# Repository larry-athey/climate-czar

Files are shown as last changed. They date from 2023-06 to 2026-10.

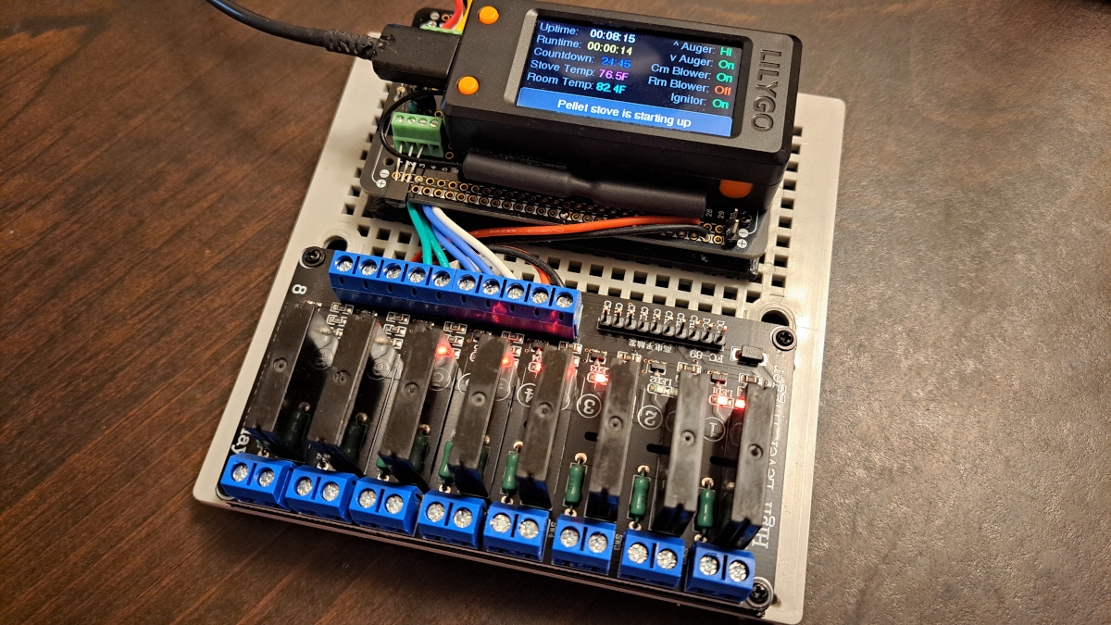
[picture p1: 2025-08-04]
Diagrams/Pellet-Stove-Controller-Assembly.jpg

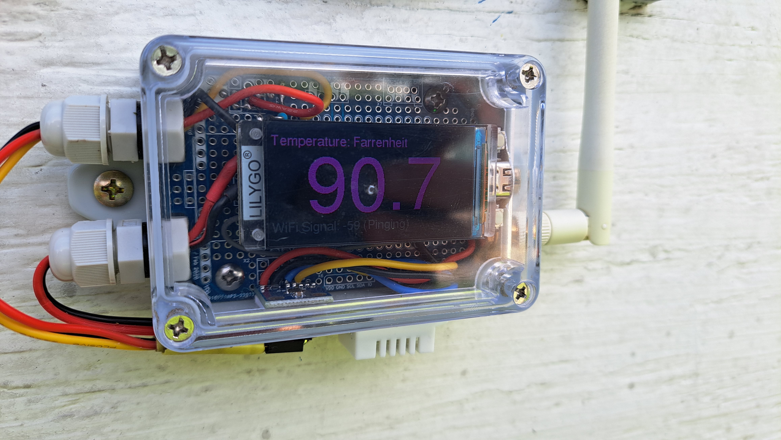
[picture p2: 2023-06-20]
CZ_Outdoor_Monitor/Outdoor-Monitor.jpg

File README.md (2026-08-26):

# Climate Czar
Universal remote climate monitoring and management system for greenhouses and indoor grow operations. No hardware brand dependencies, if you can read or control a sensor or smart switch from the command line, then it's compatible with Climate Czar.

Live demo at https://greenhouse.panhandleponics.com/cz/?CZ_THEME=1<br>
Buy a pre-built Climate Czar server at https://3dgtower.com

You may also contact me directly at https://panhandleponics.com<br>
Subscribe to the official YouTube channel at https://www.youtube.com/@PanhandlePonics

_...No, I don't use AI to design and build my projects, I actually still know how to use my brain..._

---
<br>
---

Climate Czar is a Linux based system that gathers readings from any type of sensor or switch that can be read from the command line, whether it is a local device connected to a GPIO bus or a network device. By the same token, the system will control output switches that can also be toggled from the command line. There are no brand/model hardware dependencies, you can even use it with your own custom IoT devices.

Most smart home devices are controllable from the command line of your computer over your network. For example, you can download a utility for TP-Link/Kasa devices from https://github.com/python-kasa/python-kasa for this or you can write scripts for this that use standard command line tools in Linux and MacOS. There are many other brands with this capability as well.

Virtual input sensors/switches can be created that return the average of multiple variable value sensors _(temperature, humidity, etc)_ as well as AND/OR/NOT logic gates based on multiple binary switch type input sensors.

Enabling of output switches may be over-ridden by the status of another output switch. For example, an output switch that controls exhaust fans can be disabled if another switch running a heater is turned on. However, you can manually over-ride this if need be.

Output switches really don't even have to physically exist. Since their operation is controlled with on/off bash scripts, these scripts can also be used to send email/SMS notifications or even make a curl URL call. Input sensors/switches can be assigned to multiple output switches, so you can easily receive a notification at the same time that a physical output switch is toggled on or off.

All connected devices can be assigned to separate groups which allows you to have separate dashboards for multiple greenhouses or grow operations. There's no limit to the number of attached devices and groups. This system running on an Orange Pi 3B with 8GB of RAM was tested with 500 virtual devices and still completed all read and write operations within the every-15-seconds processing loop.

This system will run effectively on a Raspberry PI or clone, or any Linux powered web server that supports PHP and MySQL. The Climate Czar server itself could actually monitor and control multiple greenhouses and grow operations in different locations if network enabled sensors and switches are utilized throughout with an on-site Raspberry Pi running an Nginx reverse proxy.

### Input Device Types
1.	Variable Value Sensor (Temperature, Humidity, pH, EC, AD Convertor, etc)
2.	Average From a Group of Variable Value Sensors
3.	Remote Switch (Float Switch, Door/Window Switch, Photocell Switch, etc)
4.	AND Gate of a Group of Remote Switches
5.	OR Gate of a Group of Remote Switches
6.	NOT Gate of a Group of Remote Switches
7.	Scheduler (unlimited on/off schedules per day)
8.	Web Console Switch (Only controllable via web UI)
9.	Raw Text Output Device (only for displaying text, cannot be used as a controller)

The virtual input devices are where the Climate Czar really shines because they allow you to consider multiple sample points before taking action. For example, having temperature sensors on the east and west ends of a greenhouse. Each one of those could be reporting significantly different temperatures at the same time. It makes more sense to turn on heating or cooling based on the average temperature.

Climate Czar is not region specific. If you have temperature sensors that only return values in Celsius and you want to work in Fahrenheit, you just convert the return value in your read script _(command line utilities like bc allow you to do floating point math in bash)_. Climate Czar merely looks at numbers and performs actions based on math, no matter what unit of measurement is used.

WiFi controlled AC outlets such as TpLink/Kasa devices have a manual on/off button on them that could allow a person to turn them on when Climate Czar says they should be off. Output switches have a One Shot option that tells the system whether to only execute the on/off script one time, or to execute the script once every minute in order to maintain the intended on/off state.

While this system was designed and tested in a 51x18 foot greenhouse, there are probably many other uses for it besides greenhouses and indoor grow operations. If you need to read numeric values from sensors or switches and turn other devices on and off based on those values, then it's likely that this system will work for what you're needing to do. It was intentionally left completely open ended for this very reason.

Again, there is no question as to whether Climate Czar is compatible with your devices. The only question is if your devices can be read or controlled from the command line. If so, then they'll work with Climate Czar.













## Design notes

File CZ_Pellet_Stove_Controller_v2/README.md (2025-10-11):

# CZ Pellet Stove Controller v2

While this project is a sub-component of Climate Czar, this pellet stove controller will run perfectly fine by itself, no need for a Climate Czar server. It is only included as a sub-component of Climate Czar since I use it in my greenhouse to manage the water temperature in my fish tanks. My greenhouse pellet stove is actually converted to a low-grade boiler, the heat that comes off the outside of the stove doesn't really provide much benefit. The England Stove Works controller died on me and I wasn't going to pay $300 for a new one when theirs doesn't have any kind of WiFi connectivity. So, here we are, a better controller that only costs $65 to build.

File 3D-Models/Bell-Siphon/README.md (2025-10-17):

Linked here from this video: https://youtube.com/shorts/Ub4dpkmLgVc

No, these aren't actually part of Climate Czar, these are just being hosted here for easy download by people who have asked me for them. These models are designed for 1/4 IBC flood and drain beds and shown in Rob Bob's video on [Chop & Flip IBC](https://www.youtube.com/watch?v=b_VROMhAoSs) aquaponics systems, and will completely dummy-proof the whole bell siphon assembly and tuning.

Rob's design uses a 3/4" stand pipe which is what the **Stand-Pipe-Funnel.stl** model is meant to be attached to. I recommend gluing this to the top your stand pipe flush with the bottom of the funnel's bowl. This expands the top of the stand pipe to 1-1/2" and helps create a more reliable siphon start so you don't end up with a siphon that just slowly overflows when the bed is full of water.

**Chop-n-Flip-Bell.stl** has a built-in siphon break tube so you don't end up with a siphon that won't stop. This will work with a stand pipe (with the funnel) up to 8" tall. Adjust the stand pipe height as needed to work with your media level. My stand pipe is 6-1/2" tall and the PVC slip fitting at the bottom raises the top to 7-1/4" with the funnel.

**NOTE:** The siphon break tube on the bell is meant to be adjusted by grinding or cutting it to a shorter length. If you want the siphon to start slowing down and breaking at a higher water level, start by taking off 1/4" from the bottom to raise the opening. Grind or cut off more as needed until you find the break point that suits you. This is somewhat like a snorkel style bell, but linear in operation instead.

I recommend printing these models with PETG filament using triple walls in order to reduce the amount of air inside the walls. This is so the bell isn't likely to float when the bed fills up with water. PETG isn't recommended because of the whole "food safe plastic" bit, it's actually because PETG is more dense than PLA and ABS and doesn't float in water with no air in the walls.

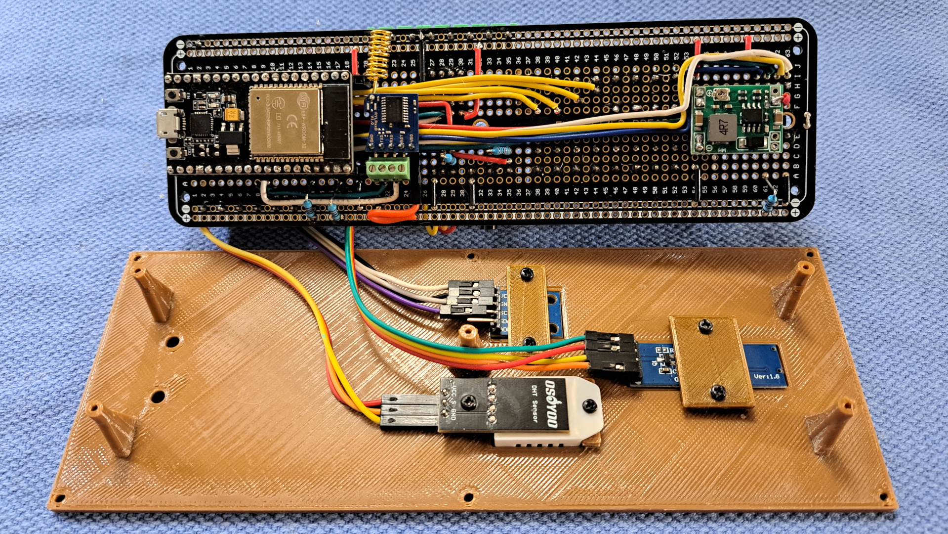
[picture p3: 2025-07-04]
Diagrams/Combo-Hub-2.jpg

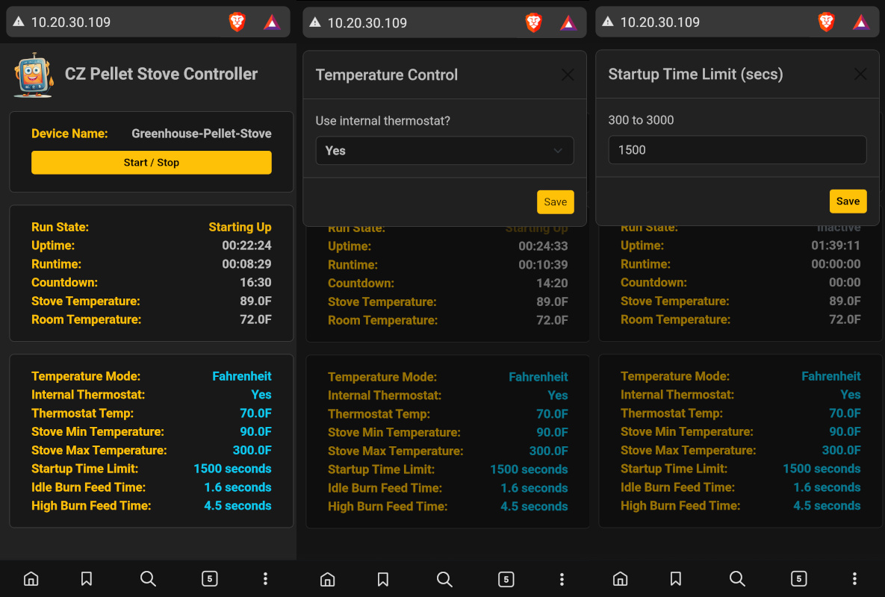
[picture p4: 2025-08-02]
Diagrams/Pellet-Stove-Controller-Web-UI.jpg

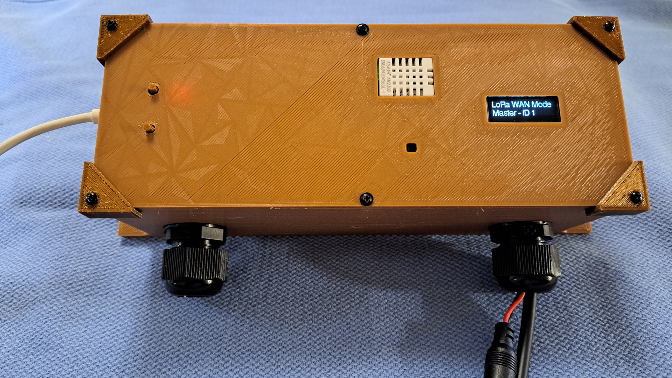
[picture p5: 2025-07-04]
Diagrams/Combo-Hub-1.jpg

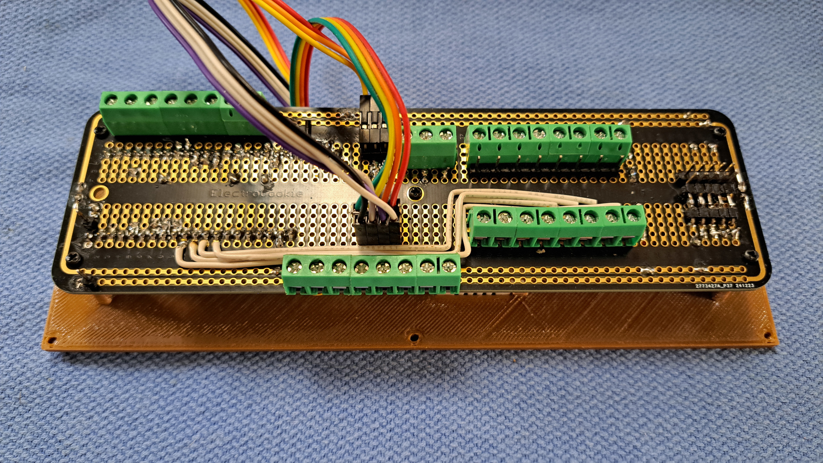
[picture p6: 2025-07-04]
Diagrams/Combo-Hub-3.jpg

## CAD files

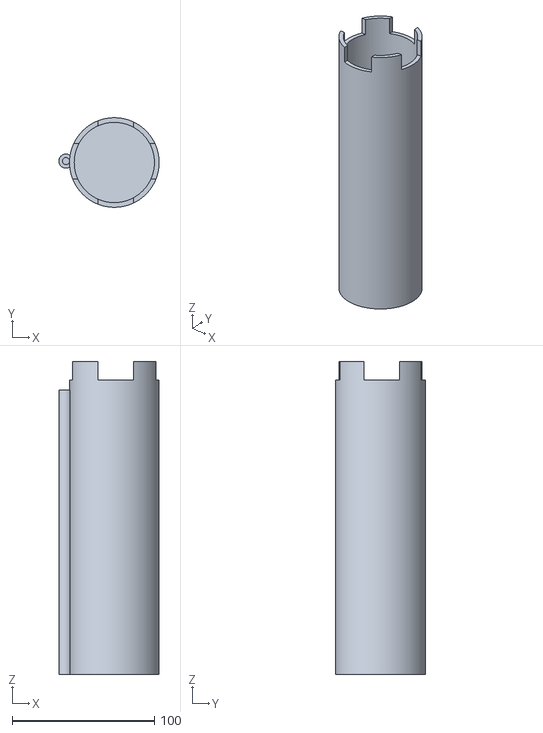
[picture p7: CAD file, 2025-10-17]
3D-Models/Bell-Siphon/Chop-n-Flip-Bell.stl
70.5 x 63.0 x 220.0

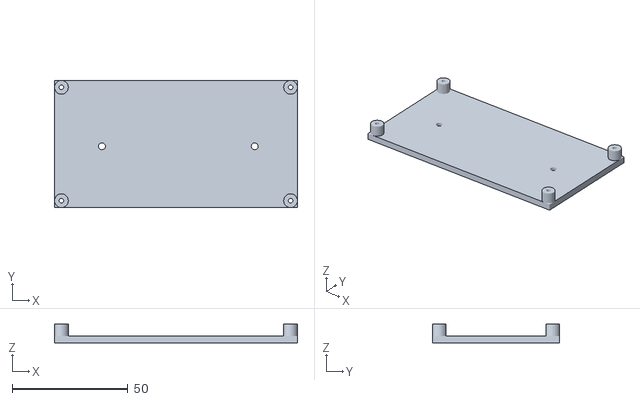
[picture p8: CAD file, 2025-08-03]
3D-Models/CZ-PSC-Relay-Mount.stl
105.0 x 55.0 x 8.00

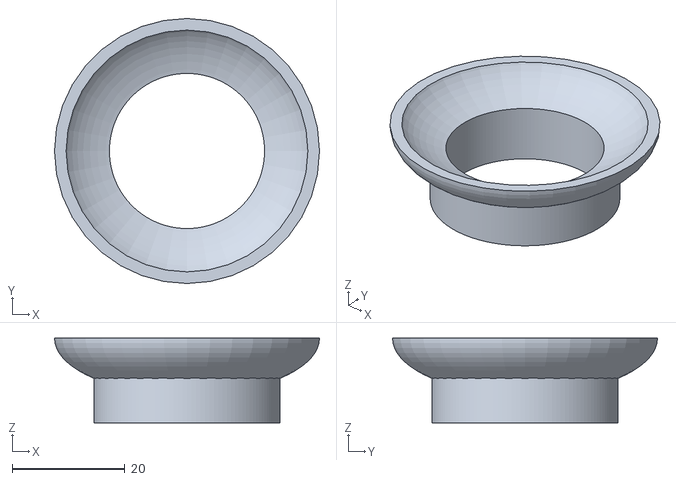
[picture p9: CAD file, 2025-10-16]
3D-Models/Bell-Siphon/Stand-Pipe-Funnel.stl
47.0 x 47.0 x 15.0

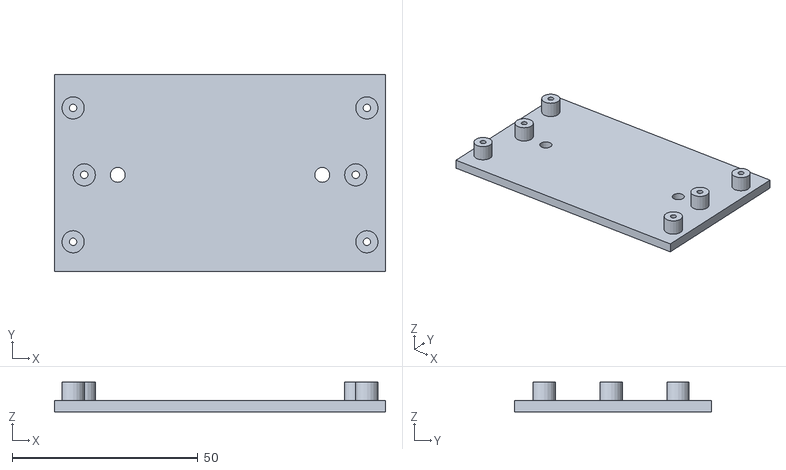
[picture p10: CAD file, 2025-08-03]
3D-Models/CZ-PSC-ESP32-Mount.stl
89.0 x 53.0 x 8.00

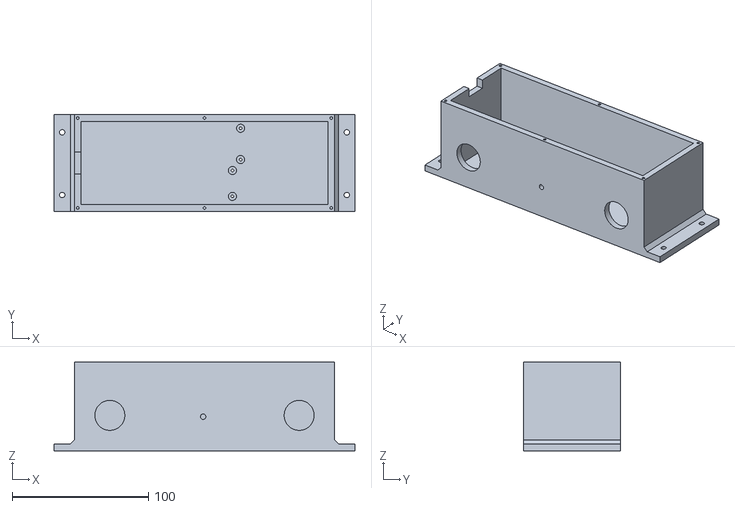
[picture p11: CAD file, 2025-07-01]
3D-Models/Combo-Hub-Back.stl
221.0 x 71.0 x 65.0

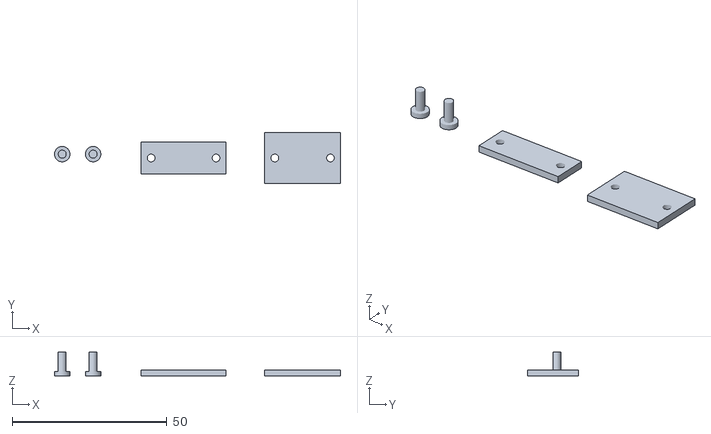
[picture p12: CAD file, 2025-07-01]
3D-Models/Combo-Hub-Addons.stl
92.5 x 16.5 x 7.75

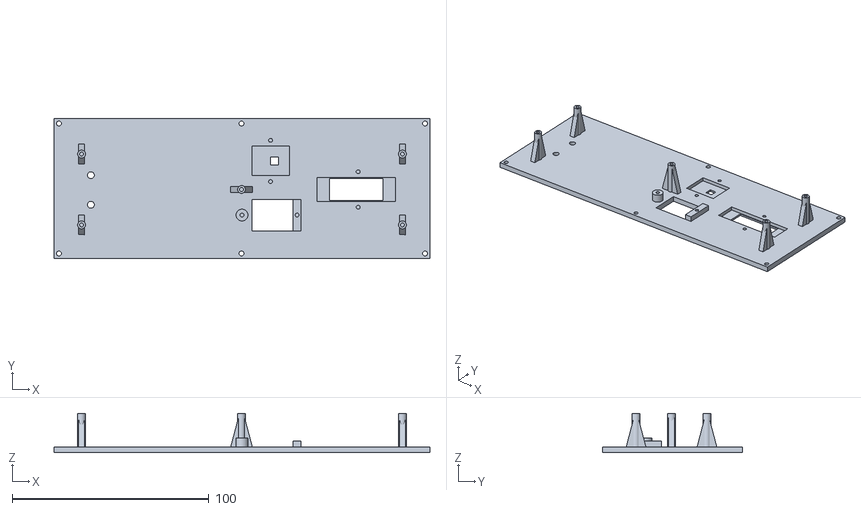
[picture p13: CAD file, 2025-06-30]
3D-Models/Combo-Hub-Front.stl
191.0 x 71.0 x 20.0

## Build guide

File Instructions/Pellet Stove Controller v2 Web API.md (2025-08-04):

# Pellet Stove Controller v2 Web API

As of the 100% rewrite of the Climate Czar Pellet Stove Controller source code, a completely new web API comes with it. This version of the controller now uses the same 100% GET web API that is featured in the new version of the Climate Czar Combo Hub.

Example CZ Pellet Stove Controller web API calls:

`curl -s -m 5 --http0.9 http://controller-ip-address/startup` (start up the pellet stove)<br>
`curl -s -m 5 --http0.9 http://controller-ip-address/temp-mode/f` (set the temperature mode to Fahrenheit)<br>
`curl -s -m 5 --http0.9 http://controller-ip-address/thermostat/70.5` (set the built-in thermostat to 70.5F)<br>

`-s` tells curl run silently and not output download progress<br>
`-m 5` tells curl to time out the connection attempt after 5 seconds<br>
`--http0.9` tells curl to use a pre version 1.0 HTTP call for compatibility safety<br>

You may notice that under heavy API use, the uptime display on the screen appears to skip seconds. This is absolutely normal and doesn't affect the actual operation of the stove. The top auger timer is an interrupt driven low speed PWM, nothing in the main loop() can affect it. The screen update and API handler run in the main loop() and heavy API use will cause lags in screen updates.

---

**/bottom-auger/0** or **/bottom-auger/1** - Turns the bottom auger motor on or off, while the controller is not performing an active run.

**/burn-mode/0** or **/burn-mode/1** - Sets the stove burn mode during an active run (0=idle, 1=high).

**/combustion/0** or **/combustion/1** - Turns the combustion blower on or off, while the controller is not performing an active run.

**/cz-stats** - Returns an HTML block with Bootstrap classes for use with Climate Czar Server in a Raw Text Output Device.

**/feed-high/??.?** - Sets the top auger feed time (in seconds) when the stove is in high burn mode.

**/feed-low/??.?** - Sets the top auger feed time (in seconds) when the stove is in idle burn mode.

**/ignitor/0** or **/ignitor/1** - Turns the ignitor on or off, while the controller is not performing an active run.

**/json-stats** - Returns a JSON object containing the stove's current operational stats for use with third-party software.

**/max-temp/??.?** - Sets the stove maximum operating temperature (C or F depending on **temp-mode**).

**/min-temp/??.?** - Sets the stove minimum operating temperature (C or F depending on **temp-mode**).

**/op-mode** - Returns the current operation mode. 0=Off, 1=Startup, 2=Running, 3=TempFail, 4=Shutdown, 5=Fault

**/reboot** - Reboots the controller, the previous run state is resumed.

**/reset** - Performs a reset of the controller startup/shutdown state, does not affect settings saved in flash memory.

**/room-blower/0** or **/room-blower/1** - Turns the room blower on or off, while the controller is not performing an active run.

**/room-temp** - Returns the current room temperature detected by the internal thermostat.

**/runtime** - Returns the current stove runtime.

**/shutdown** - Shut down the stove or cancel a start up. Shutdown time is 2x the startup time.

**/startup** - Start up the stove or cancel a shut-down, so long as the stove isn't in a thermal failure or fault state.

**/startup-timer/????** - Sets the number of seconds that the stove is allowed to reach its minimum operating temperature.

**/stove-temp** - Returns the current stove body temperature.

**/temp-mode/c** or **/temp-mode/f** - Sets the controller temperature mode to Celcius or Fahrenheit.

**/therm-temp/??.?** - Sets the target temperature of the internal thermostat (C or F depending on **temp-mode**).

**/thermostat/0** or **/thermostat/1** - Enables or disables the internal DS18B20 based thermostat.

**/toggle-run** - Toggles the current run state, this is an alternative to calling **startup** and **shutdown** separately.

**/top-auger/0** or **/top-auger/1** - Turns the top auger motor on or off, while the controller is not performing an active run.

**/uptime** - Returns the current device uptime.

**/wifi-stats** - Returns the current WiFi stats of the controller, returns the channel number and signal level.

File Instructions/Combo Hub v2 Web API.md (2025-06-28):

# Combo Hub v2 Web API

As of the 100% rewrite of the Climate Czar Combo Hub source code, a completely new web API comes with it. The Combo Hub now features a master/slave topology and the first part of the GET request is the ID number of the hub that you want to talk to. Climate Czar Server always talks directly to the master hub, which then relays API calls to slave units over LoRa WAN instead of TCP/IP.

Example Climate Czar Server web API calls:

`curl -s -m 5 --http0.9 http://master-ip-address/0/humidity` (get humidity from the master hub)<br>
`curl -s -m 5 --http0.9 http://master-ip-address/2/humidity` (get humidity from the first slave hub)<br>
`curl -s -m 5 --http0.9 http://master-ip-address/3/humidity` (get humidity from the second slave hub)<br>

`-s` tells curl run silently and not output download progress<br>
`-m 5` tells curl to time out the connection attempt after 5 seconds<br>
`--http0.9` tells curl to use a pre version 1.0 HTTP call for compatibility safety<br>

The Climate Czar Combo Hub can also communicate with your own custom LoRa WAN powered sensors. Many people have created their own Arduino/ESP32 powered devices to read things like soil temperature/moisture/pH, dissolved oxygen in aquaponics, pH probes, etc and added LoRa WAN radios to them such as the RYLR998. This web API allows you to make web calls to the hub with your own custom request message to your device and will return its response as a web request.

---

Below are explanations of all available web API calls. All of these calls are case sensitive, there is no AI at work here to decide if you're just "close enough". Breaking the rules will result in a JSON formatted failure message being returned.

**/hub-id/device-name** - Returns the device name of the selected hub.

**/hub-id/ds18b20/address/format** - Returns the temperature of a DS18B20 temperature sensor connected to the selected hub in the specified format "c" or "f". Sensor address identification is done using option #4 in the serial configuration main menu. Use ice water to determine which sensor is under test and make a note of its address. See **/hub-id/sensor-address/which-one** for an alternative to using the serial configuration for this procedure.

**/hub-id/humidity** - Returns the humidity level detected at the selected hub.

**/hub-id/light/format** - Returns the ambient light level detected at the selected hub in the specified format, "0" for Lux or "1" for percentage.

**/hub-id/lora-sensor/payload** - Returns the reading from any custom LoRa WAN powered sensor. These sensors still use the same LoRa WAN addressing scheme as a Combo Hub, ID #1 is reserved for the master hub, all other devices use LoRa WAN ID values 2 through 65535. The **"payload"** field is a free-form message and can be anything that the LoRa WAN sensor requires.

**/hub-id/reboot** - Reboots the selected hub.

**/hub-id/relay/which-one/state** - Toggles the on/off state of a specified relay port at the selected hub. **"which-one"** is a value of 1 to 15, **"state"** is 1 for on and 0 for off. Returns a JSON formatted success or failure message. Avoid toggling relay 16 unless you modify the source code to no longer use that output to perform hardware resets of the RYLR998 modem.

**/hub-id/relay-state/which-one** - Returns the on/off state of a specified relay port at the selected hub. **"which-one"** is a value of 1 to 15.

**/hub-id/sensor-address/which-one** - Returns the address and current temperatures of the specified DS18B20 sensor connected to the selected hub. Since all API results are less than 100 characters due to LoRa WAN message length limitations, the entire list of all detected DS18B20 sensors via API call isn't possible. First make a call to **/hub-id/sensor-count** to get the total number of sensors, then call this function with any number from 1 to the total number of detected sensors. This can aid in Climate Czar Server configuration without the need to connect a laptop to the hub and using serial configuration menu option #4.

**/hub-id/sensor-count** - Returns the total number of DS18B20 temperature sensors connected to the selected hub.

**/hub-id/switch/which-one** - Returns the on/off state of a specified switch port at the selected hub. **"which-one"** is a value of 1 to 8.

**/hub-id/temperature/format** - Returns the temperature detected at the selected hub in the specified format "c" or "f".

**/hub-id/uptime** - Returns the device uptime at the selected hub.

**/hub-id/wifi-stats** - Returns the device WiFi stats of the selected hub, returns the channel number and signal level.

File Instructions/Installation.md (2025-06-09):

# Installation

**Climate Czar Server** requires a Debian derivative Linux operating system in order to run its installer script. If you use Centos/Fedora, Arch, Gentoo, I'm sorry. Feel free to modify the installer script to support your Linux distribution and submit your changes. Just create an issue and attach your updated script.

This system has been tested on Raspberry Pi, Orange Pi, Banana Pi, as well as numerous x86_64 systems and works equally as well with all of them. The system has also been tested on a Raspberry Pi Zero W and everything still worked perfectly fine.

Open a terminal or SSH into your device and execute the following commands to install **Climate Czar Server**.

`git clone https://github.com/larry-athey/climate-czar`

`cd climate-czar/Undercarriage`

`./install.sh`

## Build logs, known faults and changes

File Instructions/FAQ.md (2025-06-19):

# Frequently Asked Questions

Q: Why create this when there are already so many other home automation systems that could run a greenhouse?

A: They're all overly complicated and they just continue to get even more complicated with every release. I would rather have something where the actual software is simplified. If anything complicated needs to be done, let the commands/scripts handle it so all that overhead isn't complicating the rest of the software. "Keep it stupid simple" has always been the way I write software.
___
Q: Can you recommend any specific brands of network sensors or switches/outlets to use?

A: Sorry, I can't because it's not in my budget to frivolously buy a bunch of different devices just for testing. Personally, the only third party devices that I use are TP-Link/Kasa WiFi controlled outlets. Other than that, any sensors I use are various ones used in Raspberry PI or Arduino tutorials. These are actually kids' STEM class projects, so they're certainly not that hard to build.
___
Q: Why do the device read/write loops run on 15 second intervals?

A: In my original static built version, everything was done in one long loop. The more routines I crammed into it, the longer it took to get through the loop. Splitting things into two separate loops shortens the time to get through everything and prevents pegging the CPU at 100%. The 15 second delay between cycles relieves even more CPU stress.
___
Q: Can't this 15 second delay between each read and write process cause problems?

A: This system is only intended to be used in greenhouses, indoor grow operations, basic home automation, etc. This is not intended to be used in any setting where timing has to be precise down to the second or less. If your greenhouse temperature finally hits the point where exhaust fans need to be turned on, a 15 second delay between detection time and action certainly isn't going to kill your plants. All home automation systems have delays between detection and action and some perform the action before displaying the reading in order to trick you.
___
Q: My power went out for a few seconds and when it came back, my Combo Hub won't respond.

A: It's pretty tough to destroy the ESP32 with a power outage, it takes a pretty serious surge to do it since I include a switching power supply with them rather than a linear power supply. So, I'd really suggest restarting your router or access point, even if other devices are connected just fine. I've been able to reliably reproduce this with both a Netgear and Asus router, the best I can figure is that the router didn't completely discharge and the ARP table got botched. The cure is to unplug the router or access point and give it time for all capacitors to discharge, a minute should work. Then plug it back in and power cycle your Combo Hub after that.
___
Q: Can Climate Czar monitor things like pH, EC, and DO in a hydroponics system?

A: Climate Czar can monitor anything so long as you have a sensor that can output a variable value or a binary value. There are Arduino projects/kits for both pH and EC all over the web, it's just a matter of connecting the output of them to one of the 8 inputs of the Combo Hub and pulling those values into Climate Czar with a read command.

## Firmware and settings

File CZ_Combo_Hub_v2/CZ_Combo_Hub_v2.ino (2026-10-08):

//------------------------------------------------------------------------------------------------
// Climate Czar Combo Hub v2 | (CopyLeft) 2022-Present | Larry Athey (https://panhandleponics.com)
//
// You must be using a v2.0.17 or greater ESP32 library to compile this code. Please Keep in mind
// that v3.x board libraries produce seriously BLOATED code and take much longer to compile this.
// You should also use the following URL in your preferences under Additional Boards Manager URLs.
//
// https://raw.githubusercontent.com/espressif/arduino-esp32/gh-pages/package_esp32_index.json
//
// This project uses any 38 pin ESP32 WROOM-DA / WROOM-32
//
// If you are a user of Climate Czar Combo Hub 1.1.0 there is nothing to worry about, your units
// will still continue to work with Climate Czar Server perfectly fine. This version is a complete
// rewrite from the ground up and utilizes a completely different web API.
//
// The biggest change in this version is the addition of a master/slave topography where the slave
// units are controlled via LoRa WAN. Climate Czar Server still communicates with the master unit
// via TCP/IP and HTTP calls. However, when you make an API call to anything other than unit zero,
// the API call is sent to the slave as a LoRa WAN message and the result returns to the master as
// LoRa WAN message, which is then returned to Climate Czar Server via HTTP.
//
// http://ip-address/0/humidity (get the humidity from the master unit)
// http://ip-address/2/humidity (get the humidity from the first slave unit)
// http://ip-address/3/humidity (get the humidity from the second slave unit)
//
// Aside from the local temperature & humidity at the hub via DHT22, a local BH1750 ambient light
// sensor has been added as well. This allows you to trigger daylight extension lights, or monitor
// ambient light in an indoor grow operation to trigger an alarm if your have a grow light failure.
//
// A local OLED display has also been added where you can cycle through status screens using the
// GPIO zero button on the ESP32. Support for W5500 ethernet interfaces has also been added since
// most people prefer a hard-wired network connection over a WiFi-only connection.
//
// The unit still supports unlimited DS18B20 remote temperature sensors, 8 digital inputs (ground
// the pin to trigger), and now 16 digital outputs via MCP23017 for controlling solid state relays.
// What's more, you can now configure all hub settings using a serial terminal program over USB.
//
// Climate Czar Combo Hub is now a far more sophisticated device and much easier to implement in
// your greenhouse or indoor grow operation. Until a printed circuit board is available, they're a
// bit of a lesson in patience to build because of about 30 wires that need to be cut & soldered.
// Luckily, there's no complicated electronics work involved, it's just point-to-point wiring.
//------------------------------------------------------------------------------------------------
#include "Preferences.h"         // ESP32 Flash memory read/write library
#include "SPI.h"                 // SPI bus library
#include "Wire.h"                // I2C bus library
#include "Adafruit_SSD1306.h"    // SSD1306 OLED display library
#include "Adafruit_MCP23X17.h"   // MCP23017 I2C 16 port GPIO expansion module library
#include "Arduino_GFX_Library.h" // Standard GFX library for Arduino, built with version 1.4.9
#include "FreeSans8pt7b.h"       // https://github.com/moononournation/ArduinoFreeFontFile.git
#include "DHTesp.h"              // DHT22 temperature/humidity sensor library
#include "BH1750.h"              // BH1750 light sensor library
#include "OneWire.h"             // OneWire Network communications library
#include "DallasTemperature.h"   // Dallas Semiconductor DS18B20 temperature sensor library
#include "UIPEthernet.h"         // Ethernet interface library compatible with W5500 modules
#include "WiFi.h"                // WiFi interface library
#include "ESP32Ping.h"           // ICMP (ping) library from https://github.com/marian-craciunescu/ESP32Ping
//------------------------------------------------------------------------------------------------
// Flash memory initialization
Preferences preferences;
// Server instances
WiFiServer wifiServer(80);
EthernetServer ethServer(80);
// SSD1306 display configuration (https://www.amazon.com/dp/B0925SSKHB)
#define SCREEN_WIDTH 128
#define SCREEN_HEIGHT 32
#define OLED_ADDRESS 0x3C
Adafruit_SSD1306 display(SCREEN_WIDTH,SCREEN_HEIGHT,&Wire,-1);
// I2C pins
#define SDA_PIN 21
#define SCL_PIN 22
// MCP23017 I2C address
#define MCP_ADDR 0x27
Adafruit_MCP23X17 mcp;
// DS18B20 (1-Wire)
#define ONE_WIRE_BUS 4
OneWire oneWire(ONE_WIRE_BUS);
DallasTemperature DT(&oneWire);
// DHT22
#define DHT_PIN 15
DHTesp dhtSensor;
// W5500 Ethernet (SPI)
#define SPI_MOSI 23
#define SPI_MISO 19
#define SPI_SCK 18
#define ETH_CS 5
// Status LED
#define LED 2
// Screen page button
#define BTN 0
// Inputs (digital switches)
const int inputPins[8] = {32,33,25,26,27,14,12,13};
//------------------------------------------------------------------------------------------------
bool ethConnected = false;       // Used for tracking the ethernet port connected status
bool PageCycle = true;           // If true, OLED screen changes page number on every update
bool spiStarted = false;         // Work-around since "if (SPI)" doesn't convert to a boolean value
byte ethMAC[6];                  // Placeholder for the ethernet interface MAC address
int ActiveMenu = 0;              // Used for tracking which serial config menu is in use
int ActivePage = 0;              // Used for tracking which OLED screen page to display
int CZ_pingFailures = 5;         // How many consecutive ping failures required for a reboot
int FlashInit = 0;               // Used to indicate whether the flash memory has been initialized
int LoRa_Mode = 0;               // LoRa operation mode 0=Master, 1=Slave
int LoRa_Network = 7;            // LoRa network ID 0-15 (zero is the public network)
int LoRa_Address = 1;            // LoRa network address 1-65535 (think of it like an IP address)
int Net_useDHCP = 1;             // Network use DHCP 0=False, 1=True
int Net_useWifi = 0;             // Network use WiFi 0=False, 1=True
int PingFailures = 0;            // Total number of watchdog host ping failures
long PingTimer = 0;              // Milliseconds since the last watchdog host ping test
long ScreenTimer = 0;            // Milliseconds since the last OLED screen update
unsigned long apiCount = 0;      // Counts the total number of API requests (LoRa debugging)
unsigned long slaveCount = 0;    // Counts the number of slave API requests (LoRa debugging)
String CZ_deviceName = "null";   // Network host name and LoRa device name
String CZ_Watchdog = "8.8.8.8";  // Watchdog host to ping to verify network connectivity
String LoRa_PW = "1A2B3C4D";     // LoRa domain password (8 char hex), change to something else
String Net_DNS = "";             // Network static DNS resolver
String Net_Gateway = "";         // Network static default gateway
String Net_IP = "";              // Network static IP address
String Net_Mask = "";            // Network static subnet mask
String Net_wifiSSID = "";        // Network WiFi SSID
String Net_wifiPW = "";          // Network WiFi Password
String Uptime = "00:00:00";      // Current system uptime
String Version = "2.0.1";        // Current release version of the project
//------------------------------------------------------------------------------------------------
void echoRYLR998() { // Used for debugging RYLR998 output
  char Data;
  if (Serial) {
    while (Serial2.available()) {
      Data = Serial2.read();
      Serial.print(Data);
    }
  } else {
    while (Serial2.available()) Serial2.read();
  }
}
//------------------------------------------------------------------------------------------------
void resetRYLR998() { // Performs a hardware reset of the RYLR998 using the GPIO expander module
  mcp.digitalWrite(15,LOW);
  delay(10);
  mcp.digitalWrite(15,HIGH);
  delay(100);
}
//------------------------------------------------------------------------------------------------
void setup() {
  Serial.begin(115200);
  Serial2.setRxBufferSize(1024);
  Serial2.begin(115200,SERIAL_8N1,16,17);
  delay(500);

  // Copy the WiFi MAC address for use with the W5500 and default device name
  WiFi.macAddress(ethMAC);

  GetMemory();
  if (FlashInit == 0) {
    SetMemory();
    GetMemory();
  }

  // Inidialize I2C
  Wire.begin(SDA_PIN,SCL_PIN);
  
  // Initialize inputs/outputs
  for (int i = 0; i <= 7; i ++) {
    pinMode(inputPins[i],INPUT_PULLUP); // Switch grounds the pin to register 1=true in the web API
  }                                     // 4.7K to 10K pullup resistors to +3.3 may still be needed
  pinMode(BTN,INPUT_PULLUP);
  pinMode(LED,OUTPUT);
  digitalWrite(LED,LOW);

  // Initialize MCP23017
  if (mcp.begin_I2C(MCP_ADDR)) {
    for (int i = 0; i <= 15; i ++) {
      mcp.pinMode(i,OUTPUT);
      mcp.digitalWrite(i,LOW);
    }
  } else {
    if (Serial) Serial.println(F("MCP23017 init failed!"));
  }

  // Initialize the DHT22
  dhtSensor.setup(DHT_PIN,DHTesp::DHT22);

  // Initialize SSD1306
  if (! display.begin(SSD1306_SWITCHCAPVCC,OLED_ADDRESS)) {
    if (Serial) Serial.println(F("SSD1306 init failed!"));
  }

  // Initialize Dallas Temperature bus
  DT.begin();

  // Hardware reset the RYLR998 modem using one of the GPIO expander module outputs
  mcp.digitalWrite(15,HIGH);
  delay(100);
  resetRYLR998();

  // Initialize the RYLR998 modem
  digitalWrite(LED,HIGH);
  if (Serial) Serial.println(F("Initializing the RYLR998 modem..."));
  Serial2.print(F("AT+FACTORY\r\n"));
  delay(1000);
  echoRYLR998();
  Serial2.print(F("AT+RESET\r\n"));
  delay(200);
  echoRYLR998();
  Serial2.print("AT+ADDRESS=" + String(LoRa_Address) + "\r\n");
  delay(200);
  echoRYLR998();
  Serial2.print("AT+NETWORKID=" + String(LoRa_Network) + "\r\n");
  delay(200);
  echoRYLR998();
  Serial2.print("AT+CPIN=" + LoRa_PW + "\r\n");
  delay(200);
  echoRYLR998();
  Serial2.print(F("AT+BAND=915000000\r\n"));
  delay(200);
  echoRYLR998();
  Serial2.print(F("AT+IPR=115200\r\n"));
  delay(200);
  echoRYLR998();
  Serial2.print(F("AT+PARAMETER=9,7,1,12\r\n"));
  delay(200);
  echoRYLR998();
  digitalWrite(LED,LOW);

  // Connect to the network (TCP/IP)
  if (! StartNetwork()) {
    if (Serial) Serial.println(F("\r\nNo TCP/IP network available"));
  }

  // Splash screen
  display.clearDisplay();
  display.setTextColor(SSD1306_WHITE);
  display.setFont(&FreeSans8pt7b);
  display.setTextSize(1);
  display.setCursor(0,12);
  display.println(F("CZ Combo Hub"));
  display.println("Version " + Version);
  display.display();

  PingTimer = millis();
  ScreenTimer = PingTimer;
  while (Serial.available()) Serial.read();
  while (Serial2.available()) Serial2.read();
}
//------------------------------------------------------------------------------------------------
// External function includes are used here to reduce the overall size of the main sketch.
// Go ahead and call it non-standard, but I don't like spaghetti code that goes on forever.
#include "helpers.h"  // Inline function library for data validation/formatting helpers
//------------------------------------------------------------------------------------------------
void GetMemory() { // Get the configuration settings from flash memory on startup
  preferences.begin("prefs",true);
  CZ_deviceName    = preferences.getString("cz_devicename",sanitizeHostname(""));
  CZ_pingFailures  = preferences.getUInt("cz_pingfailures",5);
  CZ_Watchdog      = preferences.getString("cz_watchdog","8.8.8.8");

  FlashInit        = preferences.getUInt("flash_init",0);

  LoRa_Mode        = preferences.getUInt("lora_mode",0);
  LoRa_Network     = preferences.getUInt("lora_network",7);
  LoRa_Address     = preferences.getUInt("lora_address",1);
  LoRa_PW          = preferences.getString("lora_pw","1A2B3C4D");

  Net_useWifi      = preferences.getUInt("net_usewifi",0);
  Net_wifiSSID     = preferences.getString("net_wifissid","");
  Net_wifiPW       = preferences.getString("net_wifipw","");

  Net_useDHCP      = preferences.getUInt("net_usedhcp",1);
  Net_IP           = preferences.getString("net_ip","0.0.0.0");
  Net_Mask         = preferences.getString("net_mask","255.255.255.0");
  Net_Gateway      = preferences.getString("net_gateway","0.0.0.0");
  Net_DNS          = preferences.getString("net_dns","0.0.0.0");
  preferences.end();
}
//------------------------------------------------------------------------------------------------
void SetMemory() { // Update flash memory with the current configuration settings
  preferences.begin("prefs",false);
  preferences.putString("cz_devicename",CZ_deviceName);
  preferences.putUInt("cz_pingfailures",CZ_pingFailures);
  preferences.putString("cz_watchdog",CZ_Watchdog);

  preferences.putUInt("flash_init",65535);

  preferences.putUInt("lora_mode",LoRa_Mode);
  preferences.putUInt("lora_network",LoRa_Network);
  preferences.putUInt("lora_address",LoRa_Address);
  preferences.putString("lora_pw",LoRa_PW);

  preferences.putUInt("net_usewifi",Net_useWifi);
  preferences.putString("net_wifissid",Net_wifiSSID);
  preferences.putString("net_wifipw",Net_wifiPW);

  preferences.putUInt("net_usedhcp",Net_useDHCP);
  preferences.putString("net_ip",Net_IP);
  preferences.putString("net_mask",Net_Mask);
  preferences.putString("net_gateway",Net_Gateway);
  preferences.putString("net_dns",Net_DNS);
  preferences.end();
}
//------------------------------------------------------------------------------------------------
bool StartNetwork() {
  bool Result = true;
  IPAddress staticIP;
  IPAddress subnet;
  IPAddress gateway;
  IPAddress dns;

  if (wifiServer) wifiServer.end();
  if (ethServer) ethServer.end();

  if (Net_useDHCP == 0) {
    int ipSegments[4];
    int maskSegments[4];
    int gwSegments[4];
    int dnsSegments[4];
    sscanf(Net_IP.c_str(),"%d.%d.%d.%d",&ipSegments[0],&ipSegments[1],&ipSegments[2],&ipSegments[3]);
    sscanf(Net_Mask.c_str(),"%d.%d.%d.%d",&maskSegments[0],&maskSegments[1],&maskSegments[2],&maskSegments[3]);
    sscanf(Net_Gateway.c_str(),"%d.%d.%d.%d",&gwSegments[0],&gwSegments[1],&gwSegments[2],&gwSegments[3]);
    sscanf(Net_DNS.c_str(),"%d.%d.%d.%d",&dnsSegments[0],&dnsSegments[1],&dnsSegments[2],&dnsSegments[3]);
    staticIP = IPAddress(ipSegments[0],ipSegments[1],ipSegments[2],ipSegments[3]);
    subnet = IPAddress(maskSegments[0],maskSegments[1],maskSegments[2],maskSegments[3]);
    gateway = IPAddress(gwSegments[0],gwSegments[1],gwSegments[2],gwSegments[3]);
    dns = IPAddress(dnsSegments[0],dnsSegments[1],dnsSegments[2],dnsSegments[3]);
    if (Net_useWifi == 1) {
      WiFi.config(staticIP,gateway,subnet,dns,dns);
    }
  }

  if (Net_useWifi == 1) {
    WiFi.begin(Net_wifiSSID,Net_wifiPW);
    long startTime = millis();
    if (Serial) Serial.print("\nConnecting to " + Net_wifiSSID + ":");
    while (WiFi.status() != WL_CONNECTED && millis() - startTime < 10000) {
      delay(500);
      if (Serial) Serial.print(F("."));
    }
    if (WiFi.status() != WL_CONNECTED) {
      if (Serial) Serial.print(F("\r\nWiFi connection failed"));
      if (Net_useDHCP == 1) {
        Net_IP = "0.0.0.0";
        Net_Mask = "255.255.255.0";
        Net_Gateway = "0.0.0.0";
        Net_DNS = "0.0.0.0"; 
      }
      Result = false;
    } else {
      if (Serial) Serial.print(F("\r\nWiFi connected"));
      Net_IP = WiFi.localIP().toString();
      Net_Mask = WiFi.subnetMask().toString();
      Net_Gateway = WiFi.gatewayIP().toString();
      Net_DNS = WiFi.dnsIP(0).toString();
      wifiServer.begin();
    }
    delay(2000);
  } else {
    if (spiStarted) {
      spiStarted = false;
      SPI.end();
    }
    ethConnected = false;
    spiStarted = true;
    SPI.begin(SPI_SCK,SPI_MISO,SPI_MOSI,ETH_CS);
    Ethernet.init(ETH_CS);

    if (Serial) Serial.print(F("\r\nConnecting to ethernet network."));
    display.clearDisplay();
    display.setTextColor(SSD1306_WHITE);
    display.setFont(&FreeSans8pt7b);
    display.setTextSize(1);
    display.setCursor(0,12);
    display.println(F("Connecting to"));
    display.println(F("ethernet network"));
    display.display();

    long startTime = millis();
    bool cableConnected = false;
    while (millis() - startTime < 10000) {
      if (Ethernet.linkStatus() == LinkON) {
        cableConnected = true;
        break;
      }
      delay(500);
      if (Serial) Serial.print(F("."));
    }
    if (! cableConnected) {
      if (Net_useDHCP == 1) {
        Net_IP = "0.0.0.0";
        Net_Mask = "255.255.255.0";
        Net_Gateway = "0.0.0.0";
        Net_DNS = "0.0.0.0"; 
      }
      spiStarted = false;
      SPI.end();
      SetMemory();
      if (Serial) Serial.print(F("\r\nNo cable detected"));
      return false;
    }

    if (Net_useDHCP == 0) {
      Ethernet.begin(ethMAC,staticIP,dns,gateway,subnet);
      if (Ethernet.localIP() == staticIP) {
        ethConnected = true;
      }
    } else {
      if (Ethernet.begin(ethMAC) > 0) {
        ethConnected = true;
      } else {
        Result = false;
        spiStarted = false;
        SPI.end();
        if (Net_useDHCP == 1) {
          Net_IP = "0.0.0.0";
          Net_Mask = "255.255.255.0";
          Net_Gateway = "0.0.0.0";
          Net_DNS = "0.0.0.0"; 
        }
      }
    }
    if (ethConnected) {
      if (Serial) Serial.print(F("\r\nEthernet connected"));
      Net_IP = Ethernet.localIP().toString();
      Net_Mask = Ethernet.subnetMask().toString();
      Net_Gateway = Ethernet.gatewayIP().toString();
      Net_DNS = Ethernet.dnsServerIP().toString();
      ethServer.begin();
    }
    if ((Serial) && (! ethConnected)) Serial.print(F("\r\nEthernet connection failed"));
    delay(2000);
  }
  SetMemory();
  return Result;
}
//------------------------------------------------------------------------------------------------
String GetDHT22(byte WhichOne) { // Get humidity and temperature from the DHT22
  TempAndHumidity DHT = dhtSensor.getTempAndHumidity();
  float T = DHT.temperature;
  float H = DHT.humidity;
  if (isnan(T)) T = 0;
  if (isnan(H)) H = 0;
  if (WhichOne == 0) {
    return String(H,1);
  } else if (WhichOne == 1) {
    return String(T,1);
  } else {
    return String(T * 9 / 5 + 32,1);
  }
}
//------------------------------------------------------------------------------------------------
String GetDS18B20(String Address, String Format) { // Get DS18B20 sensor temperature by address
  uint8_t Addr[8];
  if (stringToDeviceAddress(Address.c_str(),Addr)) {
    DT.requestTemperatures();
    oneWire.reset_search();
    float Temp = DT.getTempC(Addr);
    if (Temp != -127.0) {
      if (Format =="c") {
        return String(Temp,1);
      } else {
        return String(Temp * 9 / 5 + 32,1);
      }
    } else {
      return "nan";
    }
  }
}
//------------------------------------------------------------------------------------------------
String GetBH1750(byte WhichOne) { // Get ambient light level from the BH1750
  BH1750 lightMeter(0x23);
  if (lightMeter.begin(BH1750::CONTINUOUS_HIGH_RES_MODE)) {
    delay(200);
    float lux = lightMeter.readLightLevel();
    if (lux < 0 || lux > 65535) {
      return "-1"; // Indicate sensor error
    }
    if (WhichOne == 0) {
      return String(lux,1);
    } else {
      float light = (lux / 54612.5) * 100;
      return String(light,1);
    }
  }
}
//------------------------------------------------------------------------------------------------
String GetRelay(byte WhichOne) { // Get the on/off status of one of the 16 relay ports
  WhichOne --;
  if (WhichOne > 15) return jsonFailure;
  return String(mcp.digitalRead(WhichOne));
}
//------------------------------------------------------------------------------------------------
String GetSwitch(byte WhichOne) { // Get the on/off status of one of the eight switch ports
  WhichOne --;
  if (WhichOne > 7) return jsonFailure;
  byte State = digitalRead(inputPins[WhichOne]);
  if (State == 0) {
    State = 1;
  } else {
    State = 0;
  }
  return String(State);
}
//------------------------------------------------------------------------------------------------
String SetRelay(byte WhichOne, byte State) { // Set one of the eight relays ports on or off
  WhichOne --;
  if (WhichOne > 15) return jsonFailure;
  mcp.digitalWrite(WhichOne,State);
  return jsonSuccess;
}
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
void loop() {

}
*/
//------------------------------------------------------------------------------------------------

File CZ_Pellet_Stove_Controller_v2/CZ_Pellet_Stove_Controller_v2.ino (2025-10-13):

//------------------------------------------------------------------------------------------------
// CZ Pellet Stove Controller v2 | (CopyLeft) 2022-Present | Larry Athey (https://panhandleponics.com)
//
// Tested up to Espressif ESP32 v2.0.14 due to LilyGo requirements
//
// This code requires the LilyGo T-Display-S3 ESP32 board. You will first need to properly set up
// your Arduino IDE to upload to that board. See: https://github.com/Xinyuan-LilyGO/T-Display-S3
// Make sure that you only install the Espressif ESP32 v2.0.14 board library since the 3.x stuff
// is not backward compatible and will throw syntax errors all over the place. <Nice fkin upgrade>
//
// This project is an easy drop-in replacement for any common pellet stove controller, and brings
// WiFi connectivity to it and eliminates the need for an add-on thermostat. Aside from the stove
// now having a web UI that you can control from any mobile phone or desktop/laptop, a web API is
// also included. This allows Climate Czar Server and most any home automation software to run it.
//
// Best of all, this controller can be built for well under $100 which beats the replacement cost
// of ANY factory built controller. Even the controller for my basic England's Stove Works pellet
// stove is $299 and has no WiFi connectivity. This inflated price shouldn't comes as a surprise,
// they call it a "specialized device", even though they all work EXACTLY the same way. <facepalm>
//
// Unlike the vast majority of pellet stove controllers, this one doesn't use a cheap thermistor
// to read the stove body temperature. Thermistors are inaccurate and their accuracy changes over
// time as they age. This controller uses a digital infrared non-contact temperature sensor which
// will still have the same accuracy years from now as it has today.
//
// The optional built-in thermostat also uses a digital temperature sensor (a DS18B20) and can be
// placed up to 50 feet away, so long as unshielded twisted pair wire is used (Cat 5+ ethernet).
// This goes against their documented standards, but I use these in my greenhouse and there is no
// need for line drivers. Just run the data line and ground on a pair and run the +5v on another.
//
// As with the previous Raspberry Pi Zero based CZ Pellet Stove Controller, this version also has
// power loss recovery. If the power is lost while the stove is running, it will attempt to start
// up the stove from scratch when the power is restored. This version doesn't use SQLite to store
// settings and other data, which eliminates the possibility of data corruption if power is lost.
//
// Theory of Operation:
//
// The pellet stove starts up with a countdown timer running where constant power is sent to the
// combustion blower, bottom auger, and ignitor. The pellet feed rate is set to high burn mode
// in the startup phase. The stove body temperature is monitored during this countdown to check
// for a minimum operating temperature. The ignitor is diabled when that temperature is met and
// the room air blower is activated. The pellet feed rate then falls back to idle mode.
//
// The pellet feed operation is fairly simple. Your bottom auger spins all the time during a run.
// The top auger feeds pellets from the hopper into the bottom auger feed tube every 15 seconds.
// The top auger pulse time has two different durations for idle mode and high burn mode.
//
// If the stove body temperature fails to reach the minimum operating temperature in time, this
// initiates the stove shutdown procedure. This disables the top auger feed timer. The power to
// the combustion blower, bottom auger, and room air blower is left on for twice the length of
// the startup timer to make sure that all pellets and coals have completely burned out.
//
// The countdown timer for the shutdown process cannot be interrupted from the web UI or using
// the buttons on the ESP32. The only way to interrupt this is to make a web API call to reset
// the pellet stove controller. Complicating this is intentional so a person can't accidentally
// cause a burn-back situation and ignite the pellets in the hopper.
//------------------------------------------------------------------------------------------------
#include "WiFi.h"                // WiFi network connectivity library
#include "ESP32Ping.h"           // ICMP (ping) library from https://github.com/marian-craciunescu/ESP32Ping
#include "Arduino_GFX_Library.h" // Standard GFX library for Arduino, built with version 1.6.0
#include "FreeSans9pt7b.h"       // https://github.com/moononournation/ArduinoFreeFontFile.git 
#include "Preferences.h"         // ESP32 Flash memory read/write library
#include "Wire.h"                // I2C communications library
#include "Adafruit_MLX90614.h"   // MLX90614 non-contact temperature sensor library
#include "OneWire.h"             // OneWire Network communications library
#include "DallasTemperature.h"   // Dallas Semiconductor DS18B20 temperature sensor library
//------------------------------------------------------------------------------------------------
#define ONE_WIRE 13              // 1-Wire network pin for the DS18B20 temperature sensor
#define SCL 12                   // I2C clock pin
#define SDA 11                   // I2C data pin
#define SCREEN_BACKLIGHT 38      // Screen backlight LED pin
#define SCREEN_POWER_ON 15       // Screen power on/off pin
#define START_BTN 0              // Stove start/stop button (press and hold for 5 seconds)
#define BURN_BTN 14              // High burn mode toggle button
#define TOP_AUGER 16             // Output to the top auger SSR 
#define BOTTOM_AUGER 21          // Output to the bottom auger SSR
#define COMBUSTION_BLOWER 17     // Output to the combustion blower SSR
#define ROOM_BLOWER 18           // Output to the room air blower SSR
#define IGNITOR 44               // Output to the ignitor SSR
#define HIGH_BURN 1              // Optional external high burn mode toggle pin (ground to activate)
#define FAULT 2                  // Optional vacuum switch fault detection pin (ground to activate)
//------------------------------------------------------------------------------------------------
Arduino_DataBus *bus = new Arduino_ESP32PAR8Q(7 /* DC */, 6 /* CS */, 8 /* WR */, 9 /* RD */,39 /* D0 */, 40 /* D1 */, 41 /* D2 */, 42 /* D3 */, 45 /* D4 */, 46 /* D5 */, 47 /* D6 */, 48 /* D7 */);
Arduino_GFX *gfx = new Arduino_ST7789(bus, 5 /* RST */, 0 /* rotation */, true /* IPS */, 170 /* width */, 320 /* height */, 35 /* col offset 1 */, 0 /* row offset 1 */, 35 /* col offset 2 */, 0 /* row offset 2 */);
Arduino_Canvas_Indexed *canvas = new Arduino_Canvas_Indexed(320 /* width */, 170 /* height */, gfx);
OneWire oneWire(ONE_WIRE);
DallasTemperature DT(&oneWire);
WiFiServer Server(80);
Adafruit_MLX90614 mlx = Adafruit_MLX90614();
Preferences preferences;
hw_timer_t *timer = NULL;
//------------------------------------------------------------------------------------------------
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

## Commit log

2025-06-18 Remove LED calls
2025-06-22 ESP32 board 3.x compatibility modification
2025-06-22 More v3.x board library compatibility fixes
    [CZ_Combo_Hub_v2.ino]
2025-06-26 Bug fix on LoRa sender ID verification
    [lora_wan.h, web_api.h]
2025-06-29 Add Combo Hub case 3D models
    [Combo-Hub-Addons.stl, Combo-Hub-Back.stl, Combo-Hub-Front.stl]
2025-08-03 Add 3D models for pellet stove controller
    [CZ-PSC-ESP32-Mount.stl, CZ-PSC-Relay-Mount.stl]
